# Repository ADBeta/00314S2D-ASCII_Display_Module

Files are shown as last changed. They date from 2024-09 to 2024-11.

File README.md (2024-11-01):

# 00314S2D-ASCII 14 Segment 2 Digit LED Display Module    MkI

`00314S2D-ASCII` is a Daisychain-able 14 Segment, 2 Digit Display Module,
designed around the CH32V003 MCU.  
It receives `115200 Baud` UART Data, in standard ASCII Format, then displays
up to 2 Chars per Module. Any Additional chars will be transmitted down the 
chain of displays.

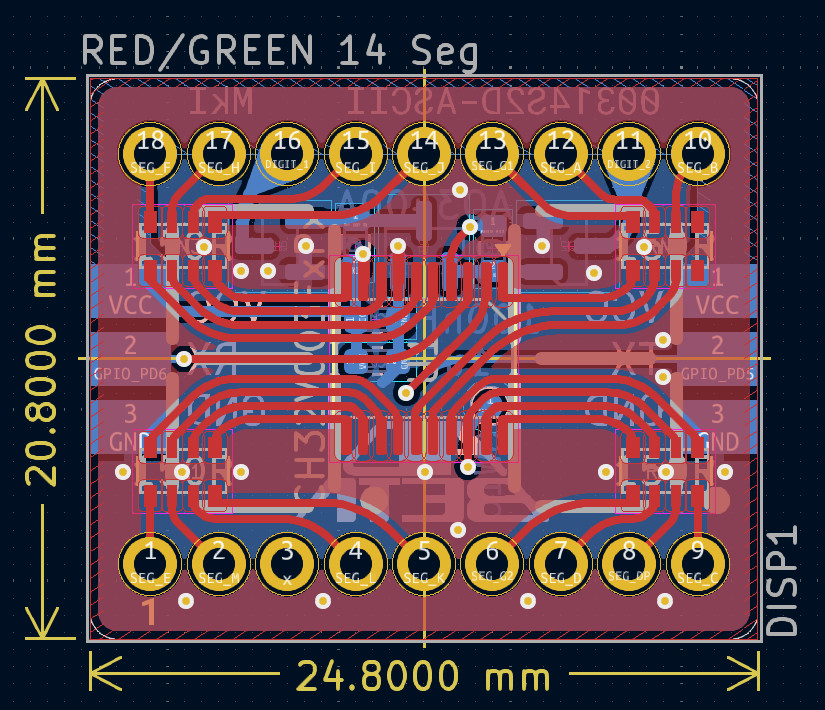
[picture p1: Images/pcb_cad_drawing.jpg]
PCB CAD

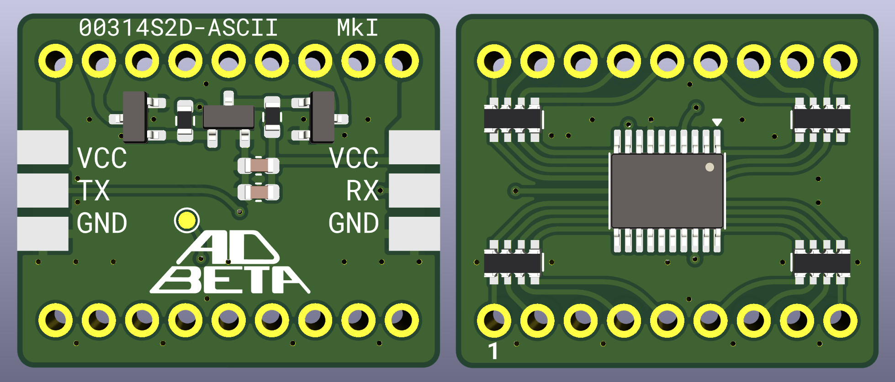
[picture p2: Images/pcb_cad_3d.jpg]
PCB 3D


## How to Use
Connect a standard UART TX line, running at 115200 Baud to the
`RX` connection of the module, it is now ready to accept data.  
Any ASCII characters will be printed to the display, when one displays
buffer is full, it will echo the data on to the next display.  
Transmit `\n` or `\r` to clear the displays, this will propegate and 
clear all displays at once.  

To Daisychain the displays, connect `TX` from one, to `RX` of the next,
along with VCC and GND - this will allow you to connect [theoretically]
infinite displays in one chain, the only limit being current on VCC.

## Building a Module
BOM
```
RN1        330R 4*0603 Resistor Array
RN2        330R 4*0603 Resistor Array
RN3        330R 4*0603 Resistor Array
RN4        330R 4*0603 Resistor Array
R1         10R 0603
R2         2K2 0603
Q1         AO3400 N-Ch MOSFET SOT-23
Q2         AO3400 N-Ch MOSFET SOT-23
Q3         AO3400 N-Ch MOSFET SOT-23
C1         100nF 0603 MLCC
C2         1uF 0603 MLCC
U1         CH32V003FxPx TSSOP-20
DISP1      Red/Green/Blue 14 Segment 2 Digit Common Cathode Display
```

## Programming
Programming is done via the SWIO TestPoint on the back of the PCB.
Once programmed, SWIO is disabled to be used as a normal GPIO.
To Reprogram the deivce, connect a programmer to the SWIO pin, and
power cycle the device - this will put the device into program mode.

1) Connect SWIO Pin
2) Apply Power to the Module
3) Run `minichlink -D` to allow NRST to be a GPIO Pin
4) Flash the binary to the IC

NOTE: `make` will do both of these steps automatically if the user 
chooses to use that toolchain

> [TODO]
> Make MkII PCB with better programming ports  
> Make MkII PCB have MCU and resistors on rear side for easier repair (?)  
> Build automatic testing jig to validate modules before displays are attached  
> Investigate segment failure issue  

----
MIT License
Copyright (c) 2024 ADBeta

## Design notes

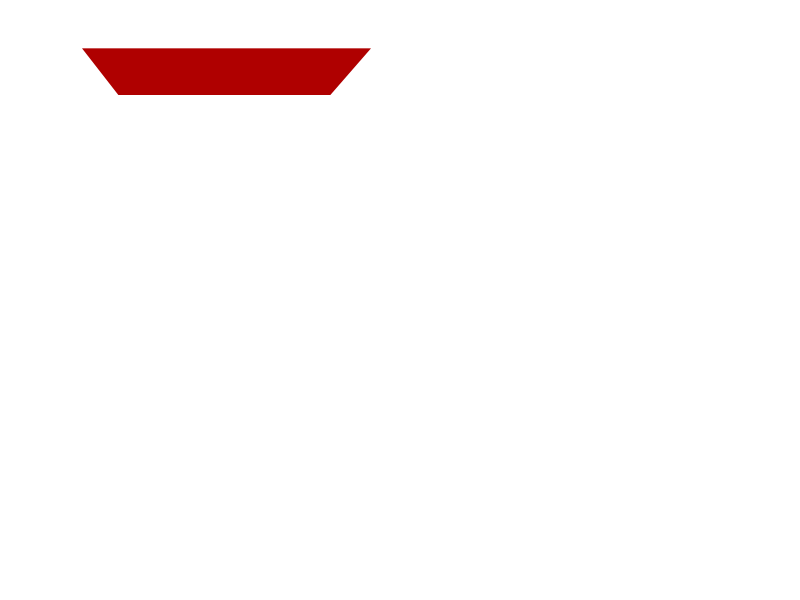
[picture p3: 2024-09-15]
Tools/starburst-font-designer/assets/a-lit.png

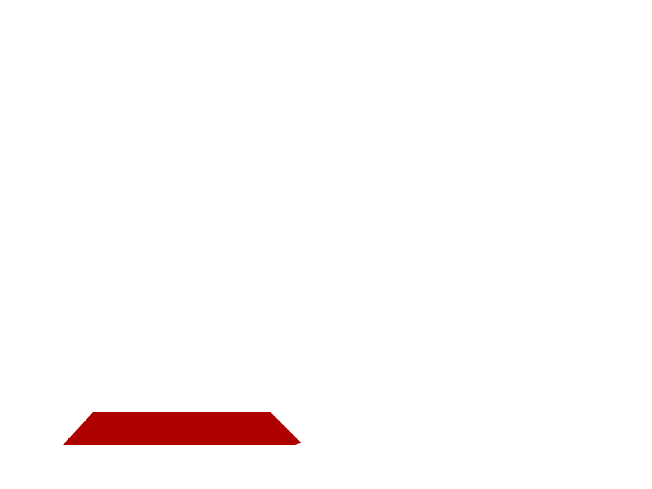
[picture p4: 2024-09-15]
Tools/starburst-font-designer/assets/d-lit.png

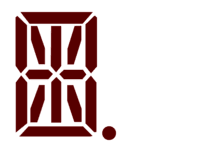
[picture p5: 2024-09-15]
Tools/starburst-font-designer/assets/small/all-dim.png

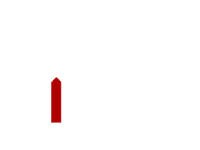
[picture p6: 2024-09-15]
Tools/starburst-font-designer/assets/small/l-lit.png

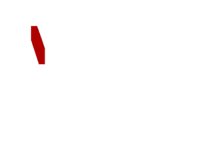
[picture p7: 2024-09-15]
Tools/starburst-font-designer/assets/small/h-lit.png

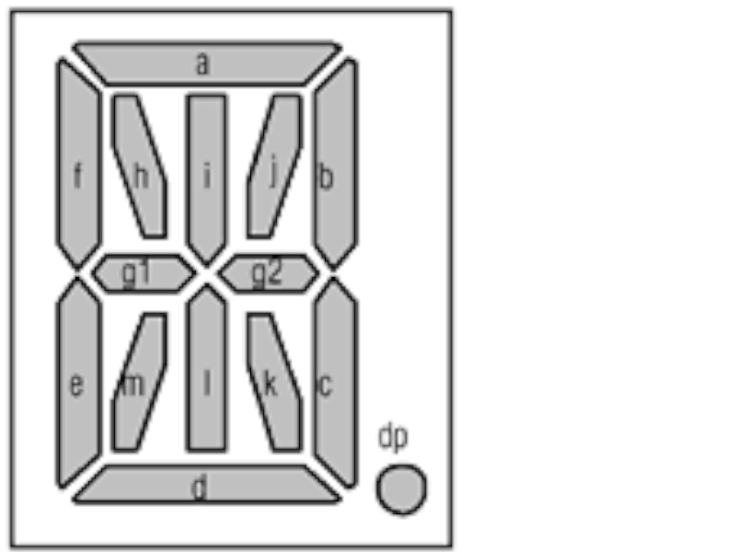
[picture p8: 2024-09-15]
Tools/starburst-font-designer/assets/segmentMap.png

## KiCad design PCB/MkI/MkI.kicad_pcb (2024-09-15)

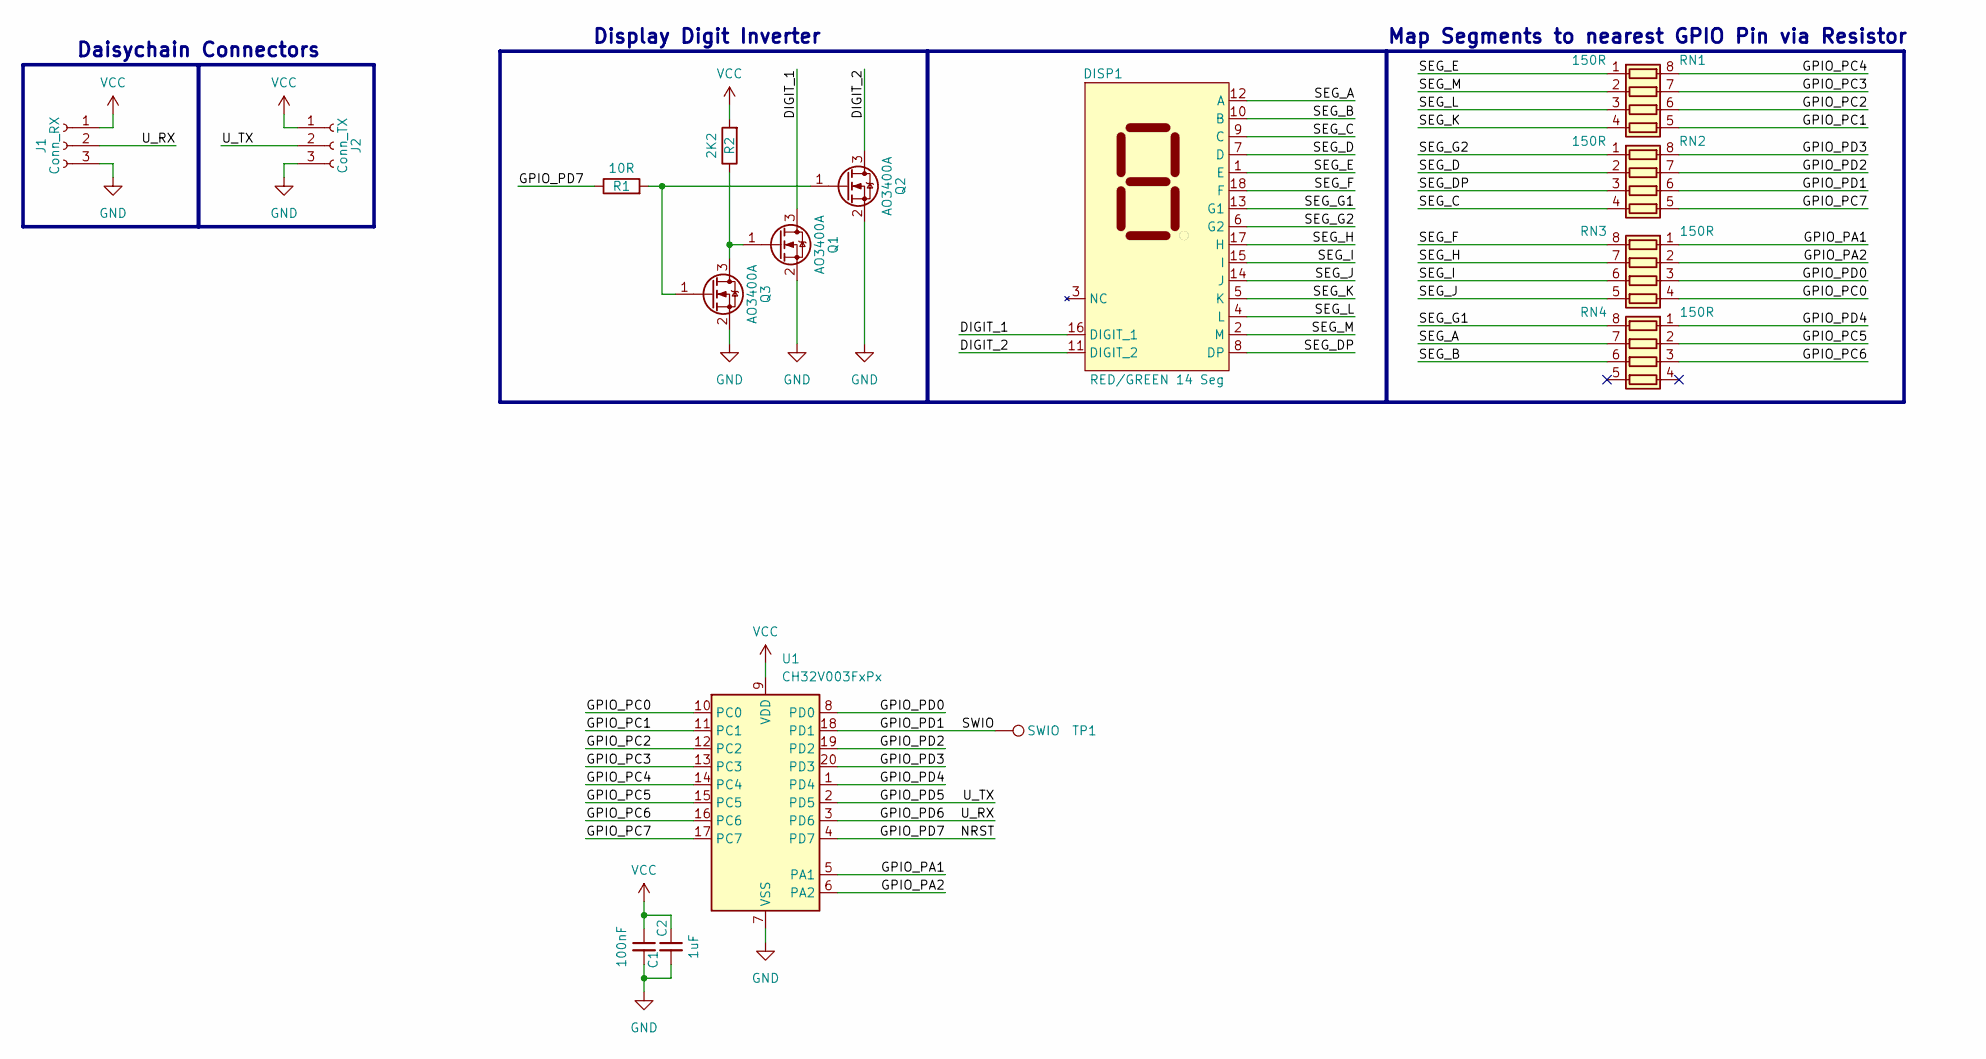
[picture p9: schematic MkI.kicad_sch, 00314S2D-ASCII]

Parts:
C1: 100nF; C_0603_1608Metric
C2: 1uF; C_0603_1608Metric
DISP1: RED/GREEN 14 Seg; 14_Seg_2_Digit_Display
J1: Conn_RX; Conn_Daisy_Chain
J2: Conn_TX; Conn_Daisy_Chain
Q1, Q2, Q3: AO3400A; SOT-23_Clean
R1: 10R; R_0603_1608Metric
R2: 2K2; R_0603_1608Metric
RN1, RN2, RN3, RN4: 150R; R_Array_Convex_4x0603
TP1: SWIO; TestPoint_Pad_D1.0mm
U1: CH32V003FxPx; TSSOP-20_4.4x6.5mm_P0.65mm

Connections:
/DIGIT_1: DISP1.16 (DIGIT_1), Q1.3 (D)
/DIGIT_2: DISP1.11 (DIGIT_2), Q2.3 (D)
/GPIO_PA1: RN3.1 (R1.1), U1.5 (PA1)
/GPIO_PA2: RN3.2 (R2.1), U1.6 (PA2)
/GPIO_PC0: RN3.4 (R4.1), U1.10 (PC0)
/GPIO_PC1: RN1.5 (R4.2), U1.11 (PC1)
/GPIO_PC2: RN1.6 (R3.2), U1.12 (PC2)
/GPIO_PC3: RN1.7 (R2.2), U1.13 (PC3)
/GPIO_PC4: RN1.8 (R1.2), U1.14 (PC4)
/GPIO_PC5: RN4.2 (R2.1), U1.15 (PC5)
/GPIO_PC6: RN4.3 (R3.1), U1.16 (PC6)
/GPIO_PC7: RN2.5 (R4.2), U1.17 (PC7)
/GPIO_PD0: RN3.3 (R3.1), U1.8 (PD0)
/GPIO_PD1: RN2.6 (R3.2), TP1.1, U1.18 (PD1)
/GPIO_PD2: RN2.7 (R2.2), U1.19 (PD2)
/GPIO_PD3: RN2.8 (R1.2), U1.20 (PD3)
/GPIO_PD4: RN4.1 (R1.1), U1.1 (PD4)
/GPIO_PD5: J2.2, U1.2 (PD5)
/GPIO_PD6: J1.2, U1.3 (PD6)
/GPIO_PD7: R1.1, U1.4 (PD7)
/SEG_A: DISP1.12 (A), RN4.7 (R2.2)
/SEG_B: DISP1.10 (B), RN4.6 (R3.2)
/SEG_C: DISP1.9 (C), RN2.4 (R4.1)
/SEG_D: DISP1.7 (D), RN2.2 (R2.1)
/SEG_DP: DISP1.8 (DP), RN2.3 (R3.1)
/SEG_E: DISP1.1 (E), RN1.1 (R1.1)
/SEG_F: DISP1.18 (F), RN3.8 (R1.2)
/SEG_G1: DISP1.13 (G1), RN4.8 (R1.2)
/SEG_G2: DISP1.6 (G2), RN2.1 (R1.1)
/SEG_H: DISP1.17 (H), RN3.7 (R2.2)
/SEG_I: DISP1.15 (I), RN3.6 (R3.2)
/SEG_J: DISP1.14 (J), RN3.5 (R4.2)
/SEG_K: DISP1.5 (K), RN1.4 (R4.1)
/SEG_L: DISP1.4 (L), RN1.3 (R3.1)
/SEG_M: DISP1.2 (M), RN1.2 (R2.1)
GND: C1.2, C2.2, J1.3, J2.3, Q1.2 (S), Q2.2 (S), Q3.2 (S), U1.7 (VSS)
unnamed: Q1.1 (G), Q3.3 (D), R2.1
unnamed: Q2.1 (G), Q3.1 (G), R1.2
VCC: C1.1, C2.1, J1.1, J2.1, R2.2, U1.9 (VDD)

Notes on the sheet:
Display Digit Inverter
Map Segments to nearest GPIO Pin via Resistor
Daisychain Connectors

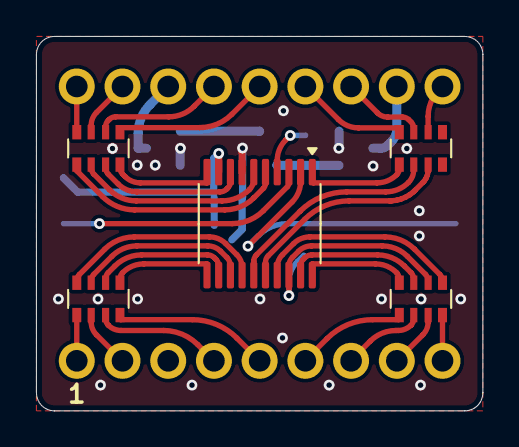
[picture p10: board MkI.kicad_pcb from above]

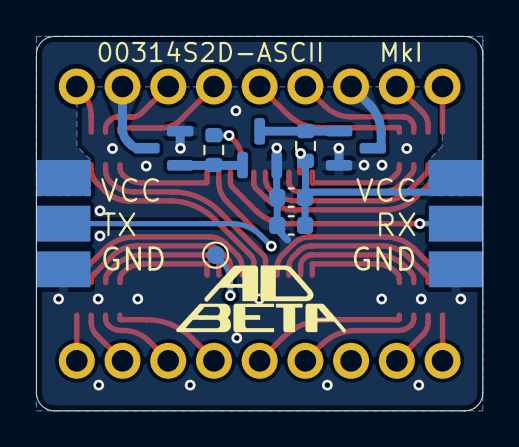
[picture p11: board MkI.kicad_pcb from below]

Board: 2 copper layers, 24.8 x 20.8 mm, 16 parts (10 on the bottom side), 39 nets.

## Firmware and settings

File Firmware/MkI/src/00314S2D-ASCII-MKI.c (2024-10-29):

/******************************************************************************
* 00314S2D-ASCII MkI
* A 2 Digit, 14 Segment Display Module using the CH32V003 MCU.
* For more information see the GitHub: 
* https://github.com/ADBeta/00314S2D-ASCII_Display_Module
*
* Functional Description:
* Each board Receives data via RX, and transmits it via TX at 115200 Baud
* When receiving data, each unit refils its internal display buffer, when it 
* is full, any incoming data is echoed directly to TX down the chain - due to
* this you can have a theoretically infinte number of displays 
*
* When power is applied, a self check takes place to look for the presense of
* a WCHLink programmer - if SWIO is asserted HIGH, a programmer is present,
* and the deivce will boot into a blank waiting mode to be programmed.
* - if the SWIO pin is left open, it boots into regular display mode
*
* Ver 0.1    14 Oct 2024 
* ADBeta (c) 2024
******************************************************************************/
#include "ch32v003fun.h"
#include "lib_gpioctrl.h"
#include "lib_uart.h"

#include "font.h"

/*** Macros ******************************************************************/
#define SYSTICK_ONE_MILLISECOND ((uint32_t)FUNCONF_SYSTEM_CORE_CLOCK / 1000)
#define SYSTICK_ONE_MICROSECOND ((uint32_t)FUNCONF_SYSTEM_CORE_CLOCK / 1000000)
#define millis() (g_systick_millis)
#define micros() (SysTick->CNT / SYSTICK_ONE_MICROSECOND)

// Timing Variables
#define DISPLAY_REFRESH_MILLIS 2

/*** Globals *****************************************************************/
// Incremented in the SysTick IRQ once per millisecond
volatile uint32_t g_systick_millis;

// Display Data Array [0] = Left    [1] = Right
uint16_t g_seg_data[2];

// Digit Pin
static const GPIO_PIN digit_pin = GPIO_PD7;

// Segment Pins
static const GPIO_PIN segment_pin[15] = {
	GPIO_PC5,    // A
	GPIO_PC6,    // B
	GPIO_PC7,    // C
	GPIO_PD2,    // D
	GPIO_PC4,    // E
	GPIO_PA1,    // F
	GPIO_PD4,    // G1
	GPIO_PD3,    // G2
	GPIO_PA2,    // H
	GPIO_PD0,    // I
	GPIO_PC0,    // J
	GPIO_PC1,    // K
	GPIO_PC2,    // L
	GPIO_PC3,    // M
	GPIO_PD1,    // DP
};

/*** Forward Declaration *****************************************************/
/// @brief Initialise the SysTick interrupt to incriment every 1 millisecond
/// @param None
/// @return None
static void systick_init(void);

/// @brief SysTick IRQ
/// @param none
/// @return none
__attribute__((interrupt))
void SysTick_Handler(void);

static void detect_programmer(void);

/// @brief Sets all segments in the display
/// @param uint16_t segment bits
/// @return None
__attribute__((always_inline))
static inline void disp_write(const uint16_t seg_data);

/// @brief Initialises the Display pins and sets it into a blank state
/// @param None
/// @return None
static void disp_init(void);

/// @brief Update which segment is visible, and set the Segment pins
/// @param None
/// @return None
static void disp_refresh(void);

/*** Main ********************************************************************/
int main(void)
{
	SystemInit();
	systick_init();

	// Checks if the SWIO Porgramming pin is connected. Waits forever if so 
	detect_programmer();
	
	// Initialise the display. Disables SWIO
	disp_init();
	
	// Setup and Initialise UART (Default Pinout)
	uart_config_t uart_conf = {
		.baudrate    = UART_BAUD_115200,
		.wordlength  = UART_WORDLENGTH_8,
		.parity      = UART_PARITY_NONE,
		.stopbits    = UART_STOPBITS_ONE,
		.flowctrl    = UART_FLOWCTRL_NONE,
	};

	uart_init(&uart_conf);	

	// Display Refresh and UART Parsing loop
	while(1)
	{
		// Refresh the display when the target millis are reached
		static uint32_t disp_last_refresh = 0;
		if(millis() - disp_last_refresh > DISPLAY_REFRESH_MILLIS)
		{
			disp_refresh();
			disp_last_refresh = millis();
		}
		
		// An interrupt will handle all display setting. Only refresh in loop
	}
}


/*** Functions ***************************************************************/
static void systick_init(void)
{
	// Reset any pre-existing configuration
	SysTick->CTLR = 0x0000;
	
	// Set the compare register to trigger once per millisecond
	SysTick->CMP = SYSTICK_ONE_MILLISECOND - 1;

	// Reset the Count Register, and the global millis counter to 0
	SysTick->CNT = 0x00000000;
	g_systick_millis = 0x00000000;
	
	// Set the SysTick Configuration
	// NOTE: By not setting SYSTICK_CTLR_STRE, we maintain compatibility with
	// busywait delay funtions used by ch32v003_fun.
	SysTick->CTLR |= SYSTICK_CTLR_STE   |  // Enable Counter
	                 SYSTICK_CTLR_STIE  |  // Enable Interrupts
	                 SYSTICK_CTLR_STCLK ;  // Set Clock Source to HCLK/1
	
	// Enable the SysTick IRQ
	NVIC_EnableIRQ(SysTicK_IRQn);
}


__attribute__((interrupt))
void SysTick_Handler(void)
{
	// Increment the Compare Register for the next trigger
	SysTick->CMP += SYSTICK_ONE_MILLISECOND;

	// Clear the trigger state for the next IRQ
	SysTick->SR = 0x00000000;

	// Increment the milliseconds count
	g_systick_millis++;
}

static void detect_programmer(void)
{
	// Set PD1 (SWIO) to INPUT_PULLDOWN - the programmer pulls HIGH
	gpio_set_mode(GPIO_PD1, INPUT_PULLDOWN);
	// Wait for line to settle
	Delay_Ms(100);
	// Detect the SWIO pins' state
	if(gpio_digital_read(GPIO_PD1) == GPIO_HIGH)
	{
		// Stop pulling SWIO so programming can happen
		gpio_set_mode(GPIO_PD1, INPUT_FLOATING);
		// Wait
		while(1) { }
	}
}

__attribute__((always_inline))
static inline void disp_write(const uint16_t seg_data)
{
	for(uint16_t seg_idx = 0; seg_idx < 15; seg_idx++)
	{
		uint8_t seg_bit = (seg_data >> seg_idx) & 0x01;
		gpio_digital_write(segment_pin[seg_idx], seg_bit);
	}
}


static void disp_init(void)
{
	// Enable Alternate GPIO Funtionality and disable SWIO
	RCC->APB2PCENR |= RCC_APB2Periph_AFIO;
	AFIO->PCFR1    |= 0x04000000;

	// TODO: Using FLASH, set the option bit to dsiable the NRST Pin

	// Set all Segment GPIO to OUTPUT, LOW
	for(uint8_t seg_pin = 0; seg_pin < 15; seg_pin++)
	{
		gpio_set_mode(segment_pin[seg_pin], OUTPUT_10MHZ_PP);
		gpio_digital_write(segment_pin[seg_pin], GPIO_LOW);
	}

	// Set the Display Control Pin to OUTPUT, LOW
	gpio_set_mode(digit_pin, OUTPUT_10MHZ_PP);
	gpio_digital_write(digit_pin, GPIO_LOW);

	// Set the global display data to 0
	g_seg_data[0] = 0x0000;
	g_seg_data[1] = 0x0000;
}


static void disp_refresh(void)
{
	// Display Selection Pin state. 0 = Left    1 = Right 
	static uint8_t digit_state = 0;

	// Blank all the segments to prevent ghosting
	disp_write(0x0000);
	// Write the current digit state
	gpio_digital_write(digit_pin, digit_state);	
	// Write the global segment data to the segment chosen
	disp_write(g_seg_data[digit_state]);

	// Invert the digit_state for the next loop
	digit_state = !digit_state;
}


/*** IRQHandler for UART ****************************************************/
/// @brief UART Receiver Interrupt handler - Puts the data received into the
/// UART Ring Buffer
/// @param None
/// @return None
void USART1_IRQHandler(void) __attribute__((interrupt));
void USART1_IRQHandler(void)
{
	if(USART1->STATR & USART_STATR_RXNE) 
	{
		// Set 2 chars on this display, after that echo to the next display.
		static uint8_t char_idx = 0;
		bool echo_flag = 0;


		// Read from the DATAR Register to reset the flag
		uint8_t recv = (uint8_t)USART1->DATAR;

		/*** Handle incomming chars ******************************************/
		// Check if the received byte is a control char
		// Newline and CR are treated the same
		if(recv == ASCII_CONTROL_LINE_FEED || 
		   recv == ASCII_CONTROL_CARRIAGE_RETURN)
		{
			// Clear displays and reset char counter
			g_seg_data[0] = 0x0000;
			g_seg_data[1] = 0x0000;
			char_idx = 0;

			// Mark this byte to be echoed forward
			echo_flag = true;

		// NOTE: Add more control char beviour at this point
		
		// Any regular ASCII Char
		} else if(recv >= 0x20 && recv <= 0x7E)
		{
			if(char_idx < 2)
			{
				// Set the corresponding char with the received data
				g_seg_data[char_idx] = ascii_font[recv - 0x20];
				char_idx++;
			} else {
				// Set flag to re-transmit the received data
				echo_flag = true;
			}
		}


		// Transmit the received byte if the flag is set
		if(echo_flag)
		{
			while(!(USART1->STATR & USART_FLAG_TC));
			USART1->DATAR = recv;
		}
	}
}

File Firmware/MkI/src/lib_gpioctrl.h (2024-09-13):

/******************************************************************************
* lib_gpioctrl
* A runtime-capable GPIO Library, with Digital Read/Write and Analog Read
*
* See GitHub for details: https://github.com/ADBeta/CH32V003_lib_gpioctrl
*
* ADBeta (c)    Aug 2024    Ver 1.2.0
******************************************************************************/
#ifndef LIB_GPIOCTRL_H
#define LIB_GPIOCTRL_H

#include <stdint.h>
#include <stddef.h>

/*** GPIO Pin Enumeration ****************************************************/
/// @breif This enum is used as binary data for pin and port addressing. 
/// 0x[PIN][PORT] - 0x 0603 6th pin of port 4 (PORTD)
/// NOTE: Little-Endian Architecture means value in memory is [PORT][PIN] order
typedef enum {
	GPIO_PA0	  = 0x0000,
	GPIO_PA1	  = 0x0100, 
	GPIO_PA2	  = 0x0200, 
	GPIO_PA3	  = 0x0300,
	GPIO_PA4	  = 0x0400,
	GPIO_PA5	  = 0x0500,
	GPIO_PA6	  = 0x0600,
	GPIO_PA7	  = 0x0700,

	GPIO_PB0	  = 0x0001,
	GPIO_PB1	  = 0x0101, 
	GPIO_PB2	  = 0x0201, 
	GPIO_PB3	  = 0x0301,
	GPIO_PB4	  = 0x0401,
	GPIO_PB5	  = 0x0501,
	GPIO_PB6	  = 0x0601,
	GPIO_PB7	  = 0x0701,

	GPIO_PC0	  = 0x0002,
	GPIO_PC1	  = 0x0102, 
	GPIO_PC2	  = 0x0202, 
	GPIO_PC3	  = 0x0302,
	GPIO_PC4	  = 0x0402,
	GPIO_PC5	  = 0x0502,
	GPIO_PC6	  = 0x0602,
	GPIO_PC7	  = 0x0702,

	GPIO_PD0	  = 0x0003,
	GPIO_PD1	  = 0x0103, 
	GPIO_PD2	  = 0x0203, 
	GPIO_PD3	  = 0x0303,
	GPIO_PD4	  = 0x0403,
	GPIO_PD5	  = 0x0503,
	GPIO_PD6	  = 0x0603,
	GPIO_PD7	  = 0x0703,

	// Map Analog Pins
	// If the CPU Is a CH32V003
	#ifdef CH32V003
	GPIO_A0	   = 0x0200,	 // PA2
	GPIO_A1	   = 0x0100,	 // PA1
	GPIO_A2	   = 0x0402,	 // PC4
	GPIO_A3	   = 0x0203,	 // PD2
	GPIO_A4	   = 0x0303,	 // PD3
	GPIO_A5	   = 0x0503,	 // PD5
	GPIO_A6	   = 0x0603,	 // PD6
	GPIO_A7	   = 0x0403,	 // PD4
	#endif
} GPIO_PIN;

/// @breif analog input pins, sorted by channel
typedef enum {
	GPIO_ADC_A0	     = 0x00,
	GPIO_ADC_A1	     = 0x01,
	GPIO_ADC_A2	     = 0x02,
	GPIO_ADC_A3	     = 0x03,
	GPIO_ADC_A4	     = 0x04,
	GPIO_ADC_A5	     = 0x05,
	GPIO_ADC_A6	     = 0x06,
	GPIO_ADC_A7	     = 0x07,
	GPIO_ADC_VREF	 = 0x08,
	GPIO_ADC_VCAL	 = 0x09,
} GPIO_ANALOG_CHANNEL;


/*** GPIO Pin Mode Enumeration ***********************************************/
/// @breif GPIO Pin Mode data. The lower nibble is the raw binary data for the
/// [R32_GPIOx_CFGLR] Register. The upper nibble is used for additional flags 
typedef enum {
	INPUT_ANALOG	   = 0x00,
	INPUT_FLOATING	   = 0x04,
	// Mapped to INPUT_PP, Sets OUTDR based on the upper nibble
	INPUT_PULLUP	   = 0x18,
	INPUT_PULLDOWN	   = 0x08,
	//
	OUTPUT_10MHZ_PP	   = 0x01,
	OUTPUT_10MHZ_OD	   = 0x05,
	//
	OUTPUT_2MHZ_PP	   = 0x02,
	OUTPUT_2MHZ_OD	   = 0x06,
	//
	OUTPUT_PP_AF	   = 0x08,
	OUTPUT_OD_AF	   = 0x0C,
} GPIO_MODE;

/*** ADC Setting Enumeration *************************************************/
/// @breif a sample of ADC clock division settings (Bits 15:11 in RCC->CFGR0)
typedef enum {
	ADC_CLOCK_DIV_2   = (uint32_t)0x00000000,
	ADC_CLOCK_DIV_32  = (uint32_t)0x00003800,
	ADC_CLOCK_DIV_64  = (uint32_t)0x00007800,
	ADC_CLOCK_DIV_128 = (uint32_t)0x0000F800,
} ADC_CLOCK_DIV;


/// @brief ADC Sample Settings. Pre-calculated Sample Bits for all channels
typedef enum {
	ADC_SAMPLE_CYCLES_3    = (uint32_t)0x00000000,
	ADC_SAMPLE_CYCLES_9    = (uint32_t)0x09249249,
	ADC_SAMPLE_CYCLES_15   = (uint32_t)0x12492492,
	ADC_SAMPLE_CYCLES_30   = (uint32_t)0x1B6DB6DB,
	ADC_SAMPLE_CYCLES_43   = (uint32_t)0x24924924,
	ADC_SAMPLE_CYCLES_57   = (uint32_t)0x2DB6DB6D,
	ADC_SAMPLE_CYCLES_73   = (uint32_t)0x36DB6DB6,
	ADC_SAMPLE_CYCLES_241  = (uint32_t)0x3FFFFFFF,
} ADC_SAMPLE_CYCLES;

/*** GPIO Output State Enumerations ******************************************/
/// @breif GPIO Pin State Enum, simple implimentation of a HIGH/LOW System
typedef enum {
	GPIO_LOW	       = 0x00,
	GPIO_HIGH	       = 0x01,
} GPIO_STATE;


/*** Registers for GPIO Port *************************************************/
/// @breif GPIO Port Register, Directly Maps to Memory starting at 
/// [R32_GPIOx_CFGLR] for each PORT Respectively
typedef struct {
	volatile uint32_t CFGLR;  // Configuration Register (lower)
	volatile uint32_t CFGHR;  // Configuration Register (upper)
	volatile uint32_t INDR;   // Input Data Register
	volatile uint32_t OUTDR;  // Output Data Register
	volatile uint32_t BSHR;   // Set/Reset Register
	volatile uint32_t BCR;	  // Port Reset Register
	volatile uint32_t LCKR;   // Lock Register
} GPIO_PORT_REG_TypeDef;
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

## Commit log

2024-09-13 MkI PCB Finished
    [MkI-B_Cu.gbr, MkI-B_Mask.gbr, MkI-B_Paste.gbr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]
2024-09-15 Added Images
    [MkI.kicad_pcb, MkI.kicad_sch]
2024-09-23 PCB Testing & Font complete
2024-10-13 Working Interrupt Handler
2024-10-13 Changed current limiting resistors
    [MkI.kicad_sch]
